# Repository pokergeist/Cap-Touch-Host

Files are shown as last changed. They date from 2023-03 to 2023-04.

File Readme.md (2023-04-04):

# Cap Touch Host Project

## Introduction

This project provides two board designs supporting capacitive touch sensing. The host board supports up to (4) cap touch sensor modules using Microchip's [CAP1188](https://www.digikey.com/en/products/detail/microchip-technology/CAP1188-1-CP-TR/3871672) IC ([datasheet](https://ww1.microchip.com/downloads/en/DeviceDoc/00001620C.pdf)) supporting (32) capacitive touch surfaces . A 5th Adafruit CAP1188 board could be used by connecting it to the MCU's Qwiic/STEMMA QT port with 5V to the VIN pin.

## The Sensor Board

The sensor board is similar to Adafruit's CAP1188 ([#1602)](https://www.adafruit.com/product/1602) board, but without level-shifting, LEDs, and access to the WAKE and ALERT pins. The ADDR_COMM and RESET pins are routed to the host board. The I2C pull-up resistors have been moved to the host board since four of five sensor modules could be in parallel, plus EEPROM or other components.. The LDO voltage regulator chip has been left on-board for better power distribution.

It should be noted that there are no pull-up resistors for the CAP1188's LED driver, so the LED drive mode will have to be changed from "open-drain" to "push-pull" mode. The output logic level can be inverted to provide a positive signal to trigger solid state relays requiring positive logic.

The default LED drive mode is open-drain such that when a switch is triggered, an n-channel MOSFET is turned-on switching the MOSFET drain and LED cathode to ground, illuminating the LED since its anode is pulled high.

The Cap Sensor inputs (CS1-8) and LED outputs (LED1-8) are not routed through the host board. Outputs can be wired directly from the sensor board when needed - otherwise, switch status can be read from the status registers via I2C.

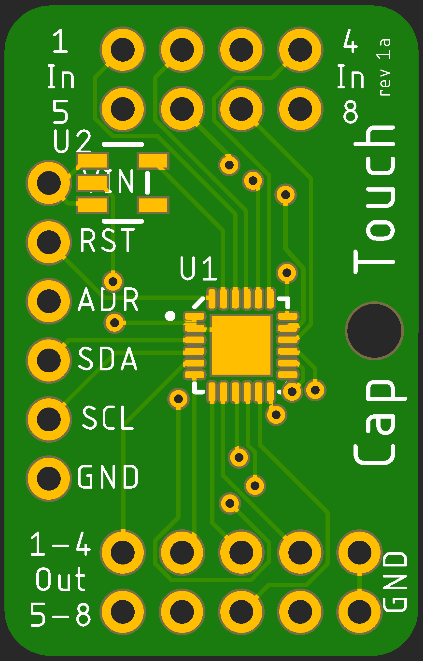
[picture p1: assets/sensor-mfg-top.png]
sensor top
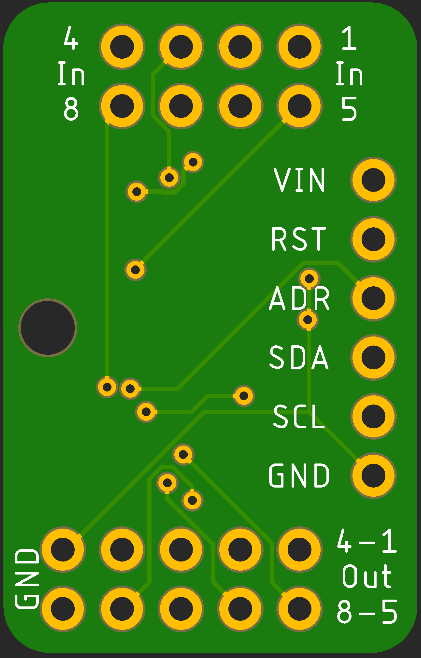
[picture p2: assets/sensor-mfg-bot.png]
sensor bottom
 

### Schematic

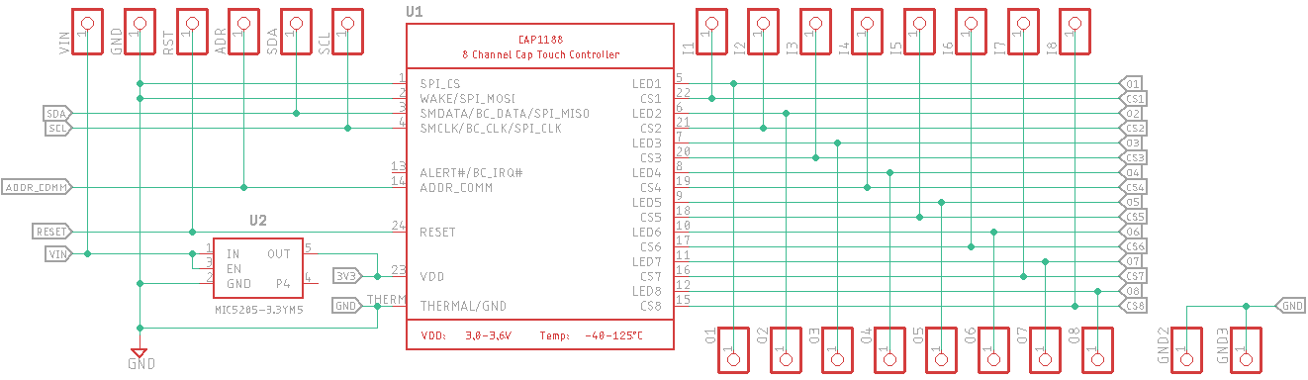
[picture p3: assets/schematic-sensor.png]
schematic


### Parts List

| Component | Description | Quan. | Part Number | Notes |
| :---: | :---: | :---: | :---: | ----- |
| U1 | Cap Touch Sensor 24VQFN | 1 | Microchip [CAP1188-1-CP-TR](https://www.digikey.com/short/jdhph3bp) | |
| U2 | LDO 3V3 Voltage Regulator SOT-23-5 | 1 | Microchip [MIC5225-3.3YM5-TR](https://www.digikey.com/short/h5855rbn) | |

2x4 and 2x5 headers and housings may be useful. Through-hole pattern: 0.1" pitch, 0.040" holes.

##  The Host Board

The host board provides a microcontroller (MCU), Adafruit QT Py SAMD21 ([#4600](https://www.adafruit.com/product/4600)) and I2C EEPROM IC, and hosts (4) Sensor boards. It provides 5V power via the USB-C pc-host or charging cable, and 3.3V I2C pull-up via the MCU's 3V3 voltage regulator.

Each of the RESET lines is pulled high and controlled by the MCU so that the MCU can make configuration changes immediately after dropping the RESET line to a logic low.

Each of the sensor module's ADDR_COMM pins are set to a different I2C address. U3 (module #1) uses the default address of 0x28. Address 0x29 (program resistor = 150kΩ) is available so that an unmodified Adafruit CAP1188 module can be attached via the QT Py MCU's Qwiic/STEMMA QT port. I2C addresses are printed on the PC board and schematic.

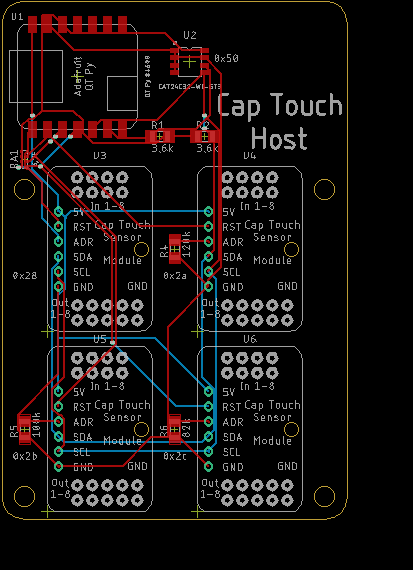
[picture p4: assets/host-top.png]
board top


### Host Board Schematic

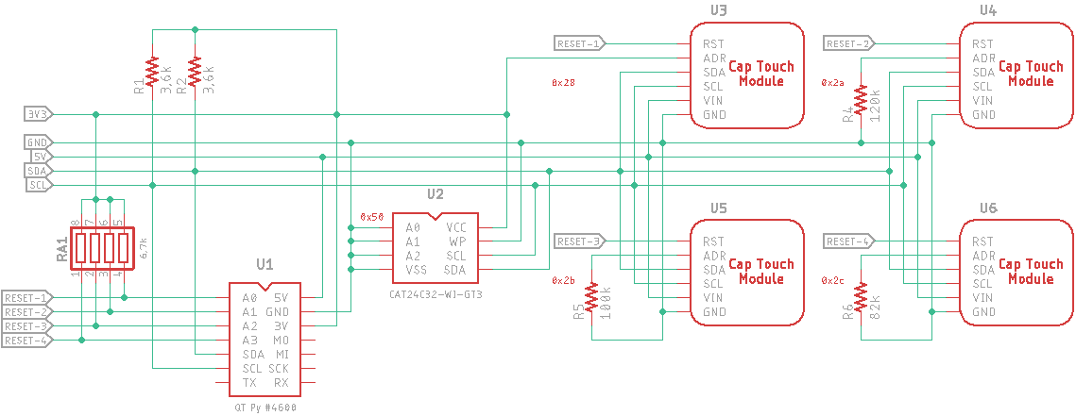
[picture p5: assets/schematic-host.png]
schematic


### Parts List

| Component | Description | Quan.  | Part Number | Notes |
| :---: | :---: | :----: | :---: | --- |
| U1 | QT PY SAMD21 MCU | 1 | Adafruit [#4600](https://www.digikey.com/short/b2fc2jh4) | Microcontroller |
| U2 |  IC EEPROM 32KBIT I2C 8-SOIC  | 1 | ON Semi [CAT24C32WI-GT3](https://www.digikey.com/short/5h0p7b04) | EEPROM memory for config. |
| RA1 | RES ARRAY 4 RES 6.8K OHM 1206 |  1 * | Bourns [CAT16-682J4LF](https://www.digikey.com/short/hrmr0547) | RESET pull-ups. |
|  R1, R2 | RES 3.3kΩ 5% 1/4W 1206 | 2 | Stackpole [RMCF1206JT3K30](https://www.digikey.com/short/57h2z201) | I2C pull-ups. |
| R4 | RES 120kΩ 1% 1/4W 1206 | 0 or 1 | Stackpole [RMCF1206FT120K](https://www.digikey.com/short/3tnptfrc) | Sets I2C address of module O4. |
| R5 | RES 100kΩ 1% 1/4W 1206 | 0 or 1 | Stackpole [RMCF1206FT100K](https://www.digikey.com/short/2pfhhrhr) | Sets I2C address of module U5. |
| R6 | RES 82kΩ 1% 1/4W 1206 | 0 or 1 | Stackpole [RMCF1206FT82K0](https://www.digikey.com/short/r0n5dq3d) | Sets I2C address of module U6. |

**Note**:

* Resistor array RA1  may not be necessary if:
  *  the GPIO lines default to a weak-pull-up INPUT mode or
  * you don't care that the **FIXME** ???
*  there's no pull-down resistor on the RESET pin of this sensor module. (10kΩ pull-down on the Adafruit board.)
* There is no resistor R3 since the address programming resistor was removed to allow use with an Adafruit CAP1188 board.

## FIXME - Add notes on RESTART, LED Drive, Invert, ...

## Status

| Date | Status |
| :---: | --- |
| 2023-04-04 | Posted board files. |
| 2023-03-13 | Posted to GitHub. |
| 2023-03-12 | Concept posted to ATMakers FB [group](https://www.facebook.com/groups/ATMakers). |

No one in the target group has an immediate need for theses boards so none are being procured at the moment. Hence there's been no testing of a delivered product or software.

## Todo

* Create board markdown files.

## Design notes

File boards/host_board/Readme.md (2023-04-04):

# Cap Touch Host Board

## The Host Board

The host board is populated with an Adafruit QT Py SAMD21 ([#4600](https://www.adafruit.com/product/4600)) microcontroller (MCU) and I2C EEPROM IC. It hosts (4) Sensor boards. It provides 5V and 3.3V power via a USB-C pc-host or charging cable connected to the MCU.

### Power

#### 5V

The Host board provides 5V power to each of the Sensor boards which is then regulated to 3.3V by each of the Sensor boards. 5V is sourced from the QT Py's USB-C 5V pin.

#### 3.3V

3.3V power is provided from the MCU's 3.3V regulator to:

* the I2C EEPROM's Vdd pin
* pull up the I2C SDA and SCL lines
* the resistor array for RESET line pull-up
* the first Sensor board's ADR pin.

### Reset

The MCU controls the Sensor RESET pins. Currently, they are pulled high via resistor array RA1. There is no pull-down resistor unless you use the Adafruit board (10kΩ). Once the MCU is ready to configure a Sensor board it changes the pin to OUTPUT mode and sets it LOW.

### I2C

Each of the sensor module's ADDR_COMM pins are set to a different I2C address. U3 (module #1) uses the default address of 0x28. Address 0x29 (program resistor = 150kΩ) is available so that an unmodified Adafruit CAP1188 module can be attached via the QT Py MCU's Qwiic/STEMMA QT port. I2C addresses are printed on the PC board and schematic.

### CAP1188 Cap Sense and LED Pins

None of the CAP1188's CS or LED pins are routed through the Host board, but rather wired directly from the Sensor board to the touch surface or switch controlled device, respectively.

### Host Board Image

board top

### Host Board Schematic

schematic

### Parts List

| Component | Description | Quan.  | Part Number | Notes |
| :---: | :---: | :----: | :---: | --- |
| U1 | QT PY SAMD21 MCU | 1 | Adafruit [#4600](https://www.digikey.com/short/b2fc2jh4) | Microcontroller |
| U2 |  IC EEPROM 32KBIT I2C 8-SOIC  | 1 | ON Semi [CAT24C32WI-GT3](https://www.digikey.com/short/5h0p7b04) | EEPROM memory for config. |
| RA1 | RES ARRAY 4 RES 6.8K OHM 1206 |  1 * | Bourns [CAT16-682J4LF](https://www.digikey.com/short/hrmr0547) | RESET pull-ups. |
|  R1, R2 | RES 3.3kΩ 5% 1/4W 1206 | 2 | Stackpole [RMCF1206JT3K30](https://www.digikey.com/short/57h2z201) | I2C pull-ups. |
| R4 | RES 120kΩ 1% 1/4W 1206 | 0 or 1 | Stackpole [RMCF1206FT120K](https://www.digikey.com/short/3tnptfrc) | Sets I2C address of module U4. |
| R5 | RES 100kΩ 1% 1/4W 1206 | 0 or 1 | Stackpole [RMCF1206FT100K](https://www.digikey.com/short/2pfhhrhr) | Sets I2C address of module U5. |
| R6 | RES 82kΩ 1% 1/4W 1206 | 0 or 1 | Stackpole [RMCF1206FT82K0](https://www.digikey.com/short/r0n5dq3d) | Sets I2C address of module U6. |

**Notes**:

* Resistor array RA1  may not be necessary because the MCU GPIO lines probably default to a weak-pull-up in INPUT mode,
* There is no resistor R3 since the address programming resistor was removed to allow use with an Adafruit CAP1188 board.

## Status

No Host or Sensor boards have been ordered yet.

## ToDo

* TBD

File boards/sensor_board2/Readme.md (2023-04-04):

# Cap Touch Sensor Board

## The Sensor Board

The sensor board is similar to Adafruit's CAP1188 ([#1602)](https://www.adafruit.com/product/1602) board, but without level-shifting, LEDs and pull-up hardware, and access to the WAKE and ALERT pins. The LDO voltage regulator chip has been left on-board for better power distribution.

#### I2C

The ADDR_COMM pins are routed to the host board where I2C comms mode is set and I2C addresses are set using programming resistors or routing to Vdd. The I2C pull-up resistors were moved to the host board to manage pull-down current better since four of five sensor modules could be in parallel, plus EEPROM or other components. The default address of Adafruit's CAP1188 board is available so that one of those can be connected to the QT Py MCU's Qwiic/STEMMA QT port and 5V.

### RESET

The RESET pins are routed to MCU on the host board and pulled high via a resistor network. The MCU pulls the RESET pins low when it's ready to configure the CAP1188.

### CAP1188 LED Drivers

#### The Default

The CAP1188 is designed to switch an LED cathode (-) to ground when a switch is active. LED anodes are pulled high with resistors. When a switch is not active, the N-channel MOSET is be off and the LED pin pulled high as well. Therefor the LED pin's state is inverted with respect to the switch state.

On startup the LEDs are switched off and the LED pins are high until the chip's configuration can be changed to invert the logic. If positive triggered solid state relays (SSRs) are connected to the LED pins, they will be switched on momentarily at startup.

### ---

It should be noted that there are no pull-up resistors for the CAP1188's LED drivers, so the LED drive mode will have to be changed from "open-drain" to "push-pull" mode to output a logic high. The output logic level can be inverted to provide a positive signal to trigger solid state relays requiring positive logic.

The CAP1188's default LED drive mode is open-drain such that when a switch is triggered, an n-channel MOSFET is turned-on switching the MOSFET drain and LED cathode to ground, illuminating the LED whos anode is pulled high.

The Cap Sensor's inputs (CS1-8) and LED outputs (LED1-8) are not routed through the host board. Outputs can be wired directly from the sensor board when needed - otherwise, switch status can be read from the status registers via I2C.

..sensor top sensor bottom

### Schematic

schematic

### Parts List

| Component | Description | Quan. | Part Number |
| :---: | :---: | :---: | :---: |
| U1 | Cap Touch Sensor 24VQFN | 1 | Microchip [CAP1188-1-CP-TR](https://www.digikey.com/short/jdhph3bp) |
| U2 | LDO 3V3 Voltage Regulator SOT-23-5 | 1 | Microchip [MIC5225-3.3YM5-TR](https://www.digikey.com/short/h5855rbn) |

2x4 and 2x5 headers and housings may be useful. Through-hole pattern: 0.1" pitch, 0.040" holes.

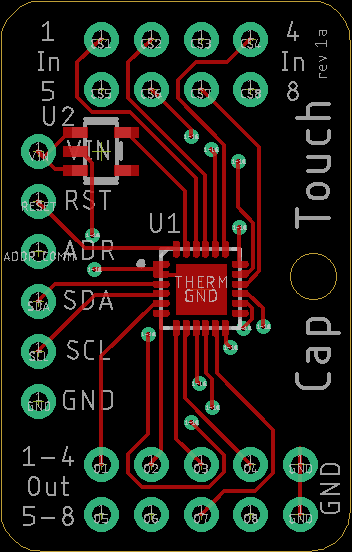
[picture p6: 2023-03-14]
assets/sensor-top.png

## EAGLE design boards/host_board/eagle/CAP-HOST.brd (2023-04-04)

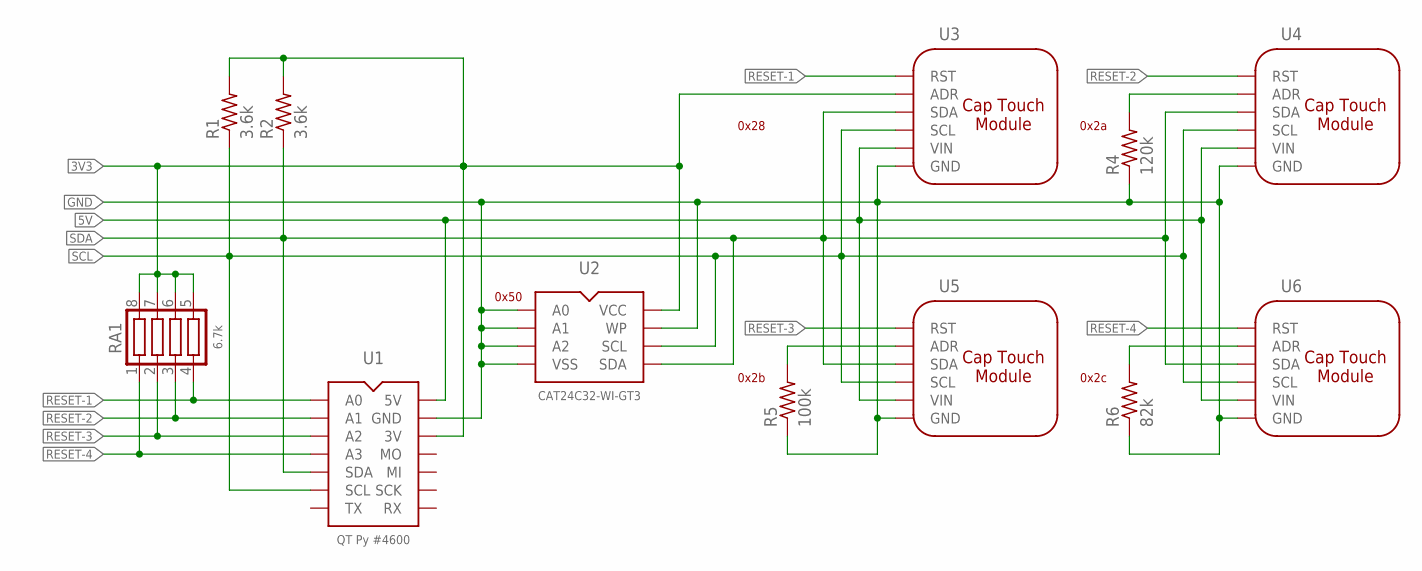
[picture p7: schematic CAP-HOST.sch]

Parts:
R1, R2: 3.6k; R1206
R4: 120k; R1206
R5: 100k; R1206
R6: 82k; R1206
RA1: 6.7k; RES-NET-1206
U1: QT Py #4600; QT_PY-CASTL
U2: CAT24C32-WI-GT3; SOIC-8-ON
U3, U4, U5, U6: CAP-SENSOR-INTF; CAP-TOUCH-MODULE-2

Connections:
3V3: R1.2, R2.2, RA1.5, RA1.6, RA1.7, RA1.8, U1.3V3 (3V), U2.P$8 (VCC), U3.ADR
5V: U1.5V, U3.VIN, U4.VIN, U5.VIN, U6.VIN
GND: R4.1, R5.1, R6.1, U1.GND, U2.P$1 (A0), U2.P$2 (A1), U2.P$3 (A2), U2.P$4 (VSS), U2.P$7 (WP), U3.GND, U4.GND, U5.GND, U6.GND
unnamed: R5.2, U5.ADR
unnamed: R6.2, U6.ADR
unnamed: R4.2, U4.ADR
RESET-1: RA1.4, U1.A0, U3.RST
RESET-2: RA1.3, U1.A1, U4.RST
RESET-3: RA1.2, U1.A2, U5.RST
RESET-4: RA1.1, U1.A3, U6.RST
SCL: R1.1, U1.SCL, U2.P$6 (SCL), U3.SCL, U4.SCL, U5.SCL, U6.SCL
SDA: R2.1, U1.SDA, U2.P$5 (SDA), U3.SDA, U4.SDA, U5.SDA, U6.SDA

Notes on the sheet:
0x28
0x2a
0x2c
0x2b
0x50

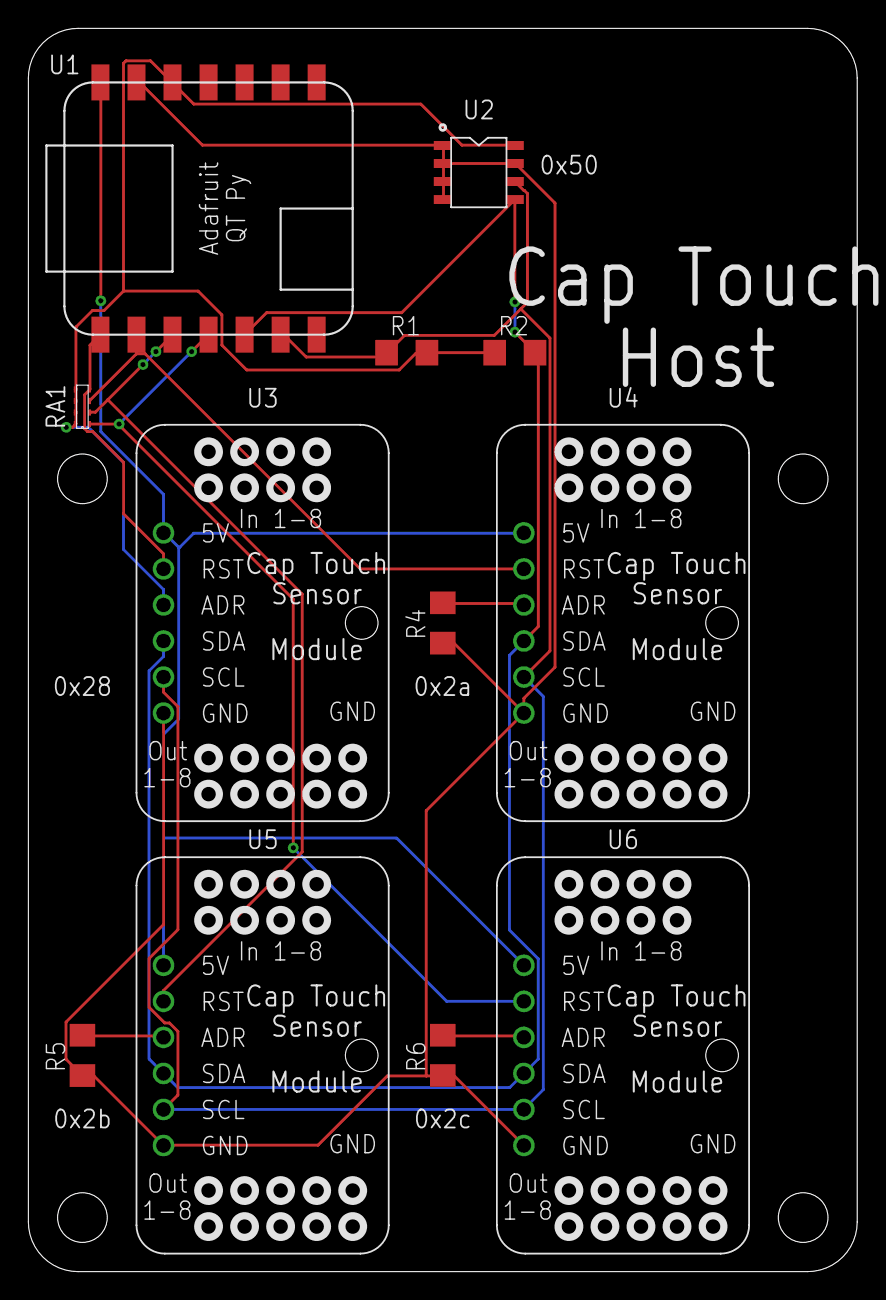
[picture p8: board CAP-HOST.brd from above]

Board: 2 copper layers, 58.4 x 87.6 mm, 12 parts (0 on the bottom side), 12 nets.

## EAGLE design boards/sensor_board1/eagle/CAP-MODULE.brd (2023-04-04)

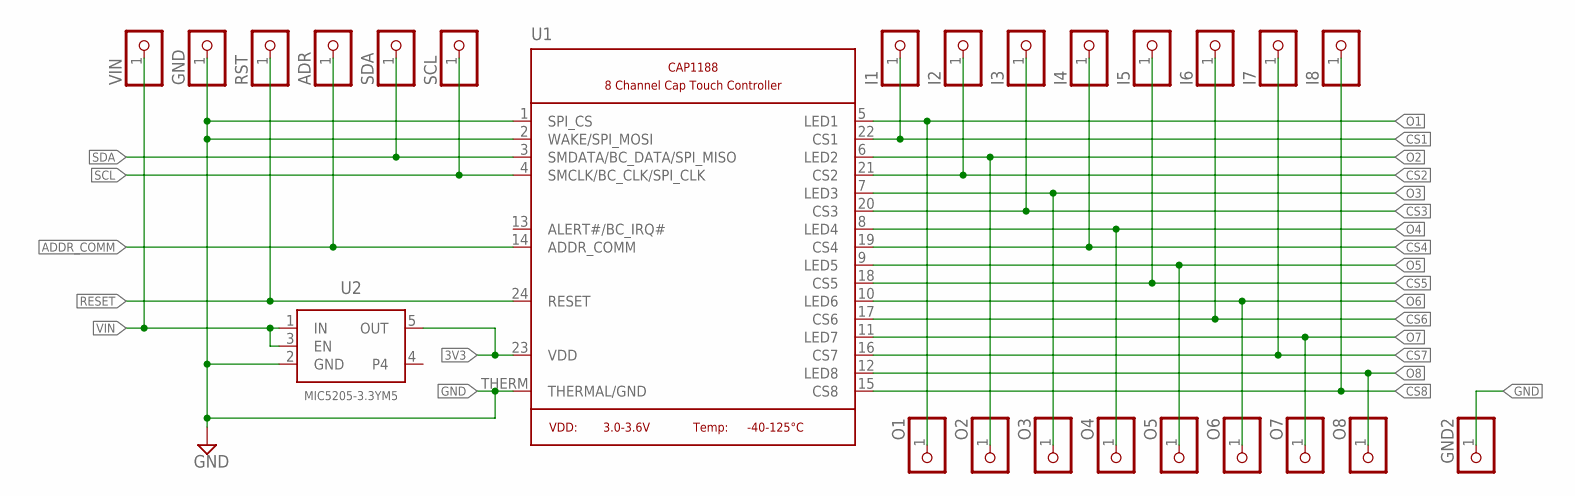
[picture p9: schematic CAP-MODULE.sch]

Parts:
ADR: PINHD-1X1CB; 1X01-CLEANBIG
GND, GND2: PINHD-1X1CB; 1X01-CLEANBIG
I1, I2, I3, I4, I5, I6, I7, I8: PINHD-1X1CB; 1X01-CLEANBIG
O1, O2, O3, O4, O5, O6, O7, O8: PINHD-1X1CB; 1X01-CLEANBIG
RST: PINHD-1X1CB; 1X01-CLEANBIG
SCL: PINHD-1X1CB; 1X01-CLEANBIG
SDA: PINHD-1X1CB; 1X01-CLEANBIG
U1: MICROBUILDER_CAP1188; MICROBUILDER_QFN24_4MM_SMSC
U2: MIC5205-3.3YM5; MICROBUILDER_SOT23-5
VIN: PINHD-1X1CB; 1X01-CLEANBIG

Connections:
3V3: U1.23 (VDD), U2.5 (OUT)
ADDR_COMM: ADR.1, U1.14 (ADDR_COMM)
CS1: I1.1, U1.22 (CS1)
CS2: I2.1, U1.21 (CS2)
CS3: I3.1, U1.20 (CS3)
CS4: I4.1, U1.19 (CS4)
CS5: I5.1, U1.18 (CS5)
CS6: I6.1, U1.17 (CS6)
CS7: I7.1, U1.16 (CS7)
CS8: I8.1, U1.15 (CS8)
GND: GND.1, GND2.1, U1.1 (SPI_CS), U1.2 (WAKE/SPI_MOSI), U1.THERM (THERMAL/GND), U2.2 (GND)
O1: O1.1, U1.5 (LED1)
O2: O2.1, U1.6 (LED2)
O3: O3.1, U1.7 (LED3)
O4: O4.1, U1.8 (LED4)
O5: O5.1, U1.9 (LED5)
O6: O6.1, U1.10 (LED6)
O7: O7.1, U1.11 (LED7)
O8: O8.1, U1.12 (LED8)
RESET: RST.1, U1.24 (RESET)
SCL: SCL.1, U1.4 (SMCLK/BC_CLK/SPI_CLK)
SDA: SDA.1, U1.3 (SMDATA/BC_DATA/SPI_MISO)
VIN: U2.1 (IN), U2.3 (EN), VIN.1

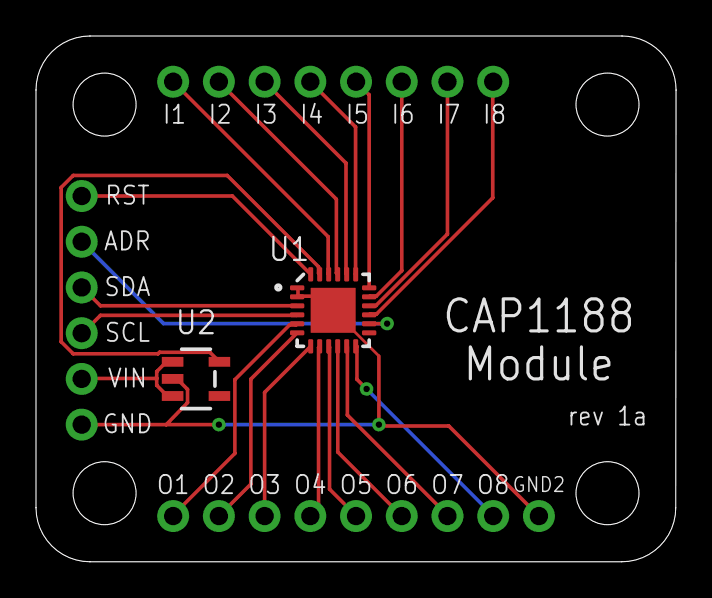
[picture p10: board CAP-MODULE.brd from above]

Board: 2 copper layers, 35.6 x 29.2 mm, 25 parts (0 on the bottom side), 23 nets.

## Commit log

2023-04-04 eagle board files & readme
    [CAP-MODULE.brd, CAP-MODULE.sch, CAP-SENSE-SLIM.brd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]
2023-04-04 and the host board
    [CAP-HOST.brd, CAP-HOST.sch]
2023-04-04 fixed dir path
    [CAP-HOST.brd, CAP-HOST.sch]
2023-04-04 board readme files
